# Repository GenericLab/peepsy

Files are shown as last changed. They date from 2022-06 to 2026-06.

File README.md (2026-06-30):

# Peepsy
Simple continuity tester based on Continuity Tester by David Johnson-Davies - http://www.technoblogy.com/show?1YON

# diy-CAD Handouts
diy-CAD (do-it-yourself Children Aided Design): The core idea of the workshop-kit is tool for creative designs of printed circuit boards, introducing basic concepts of Open Hardware being something to re-design for your own use. 

Read more about the creative PCB design methodology on this wiki: https://www.hackteria.org/wiki/Diy-CAD

## the schematics
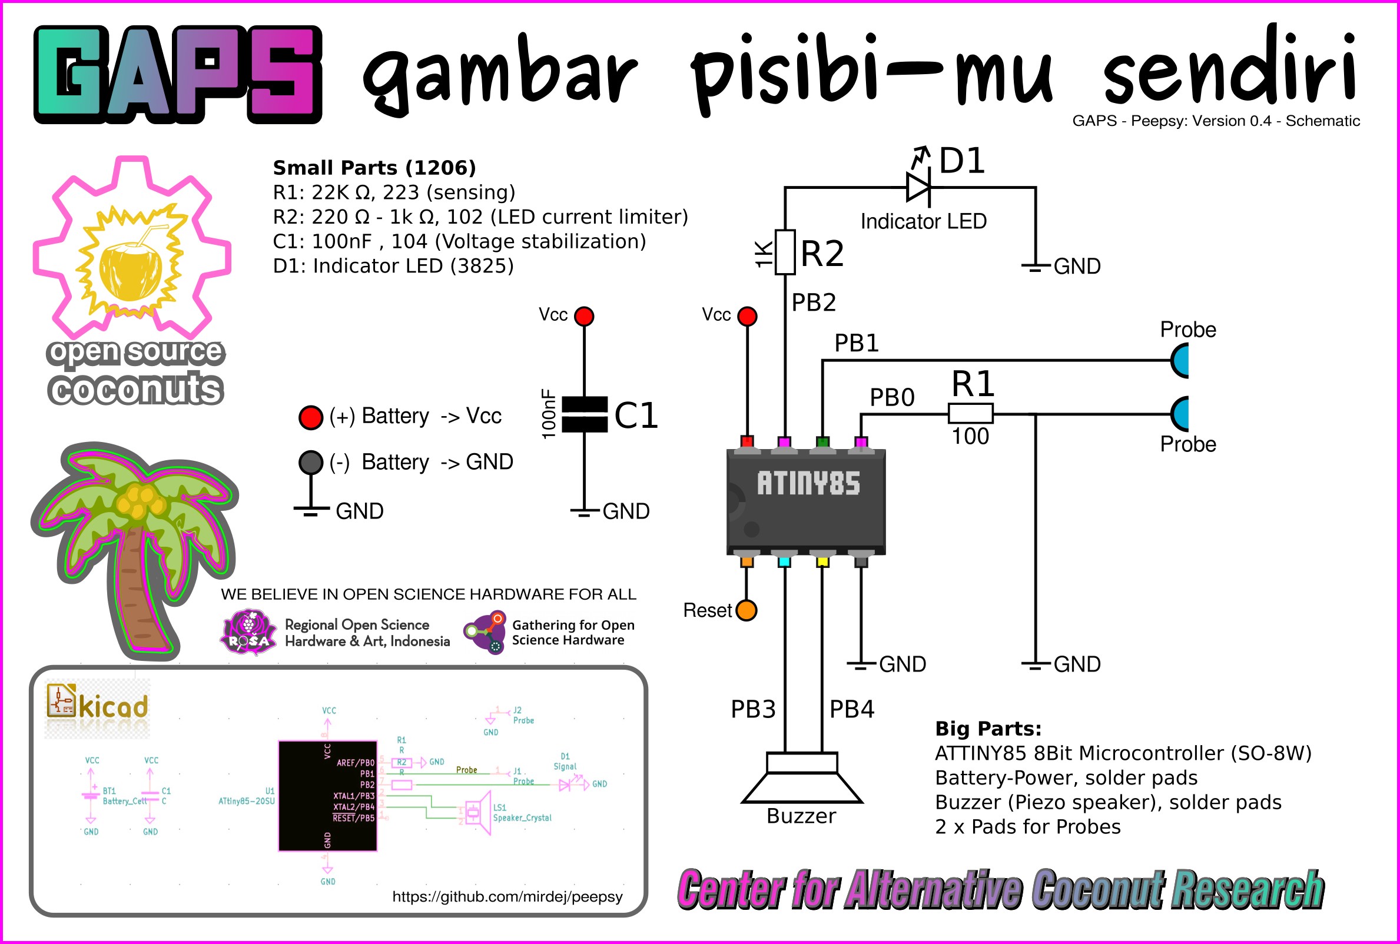
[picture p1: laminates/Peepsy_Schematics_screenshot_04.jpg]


## the BOM also know as the parts
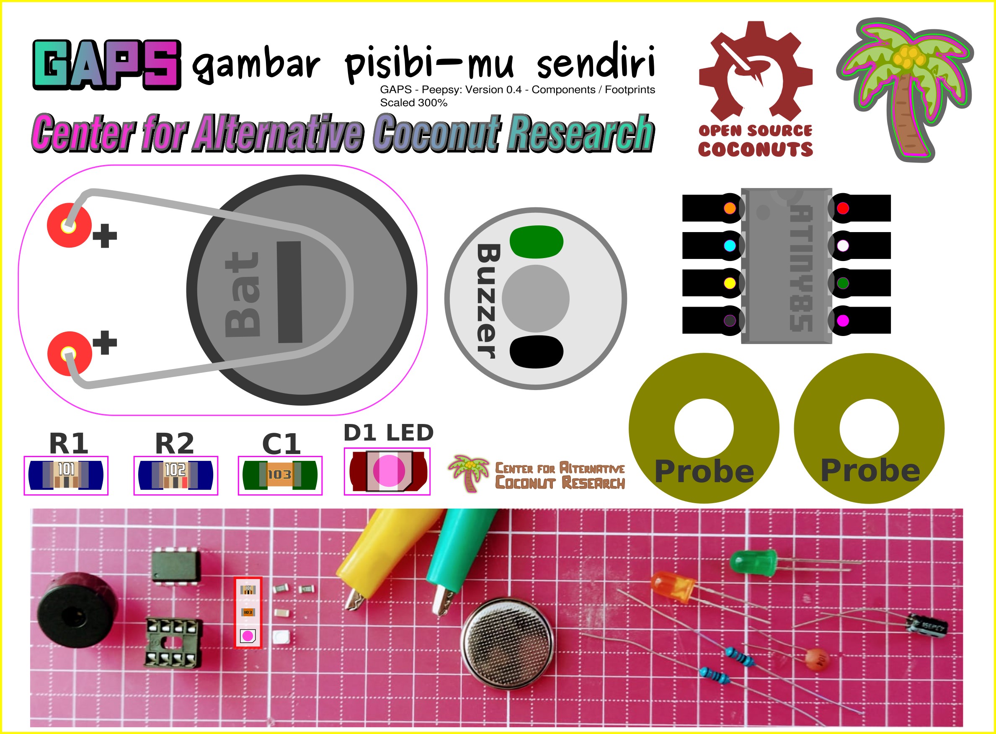
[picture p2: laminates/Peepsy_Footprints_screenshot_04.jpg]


# GAPS Workshops
## GAPS (GaPiSen) | gambar pisibi-mu sendiri - Creative PCB-design Workshop with Diy-CAD, Lifepatch 30. June 2022
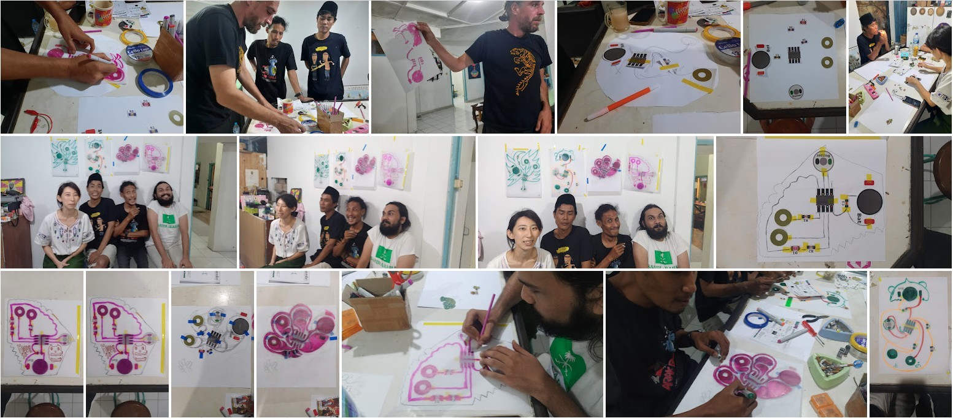
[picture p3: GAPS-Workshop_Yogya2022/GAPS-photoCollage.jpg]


## GAPS - Creative PCB-design Workshop, Electronic Wonderland August 2022
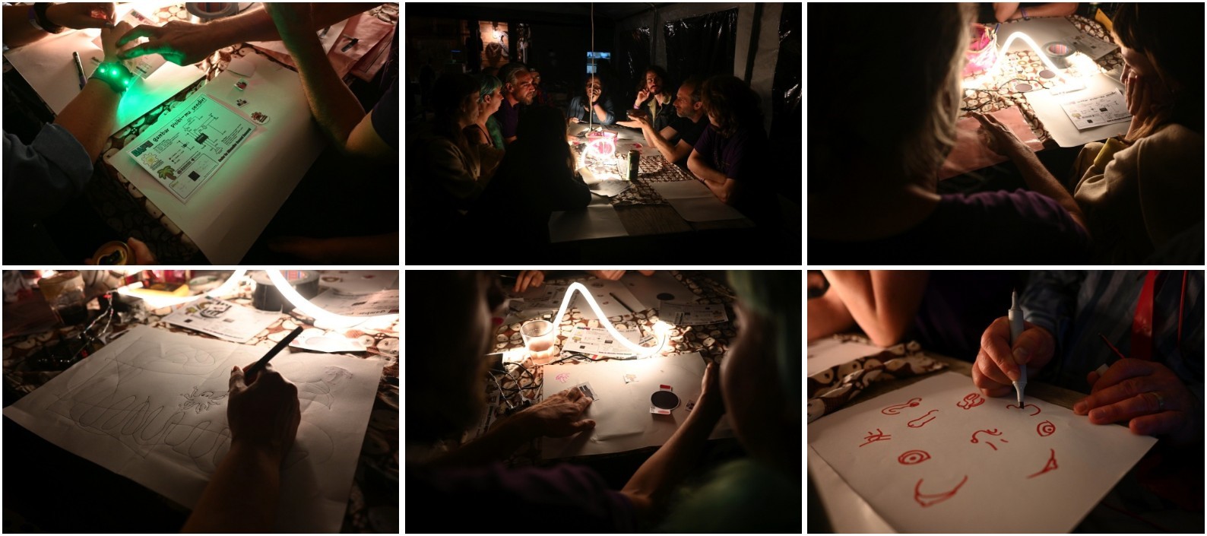
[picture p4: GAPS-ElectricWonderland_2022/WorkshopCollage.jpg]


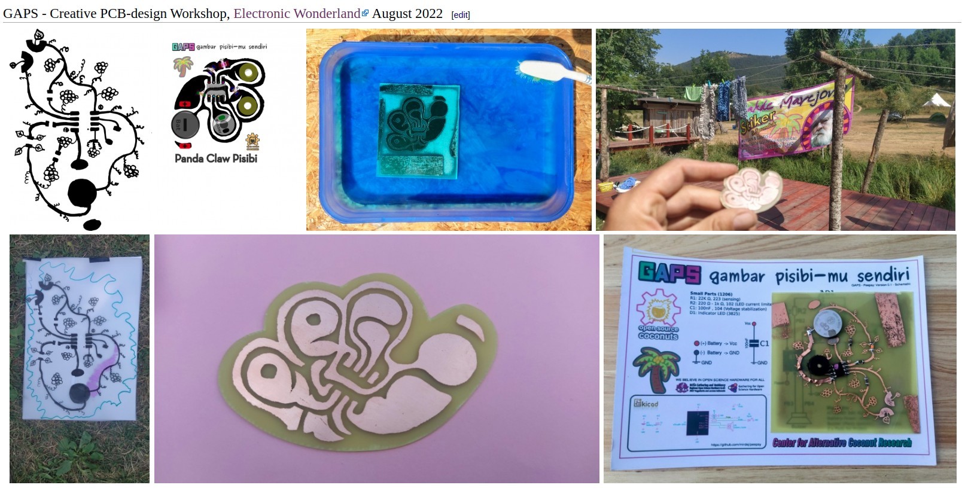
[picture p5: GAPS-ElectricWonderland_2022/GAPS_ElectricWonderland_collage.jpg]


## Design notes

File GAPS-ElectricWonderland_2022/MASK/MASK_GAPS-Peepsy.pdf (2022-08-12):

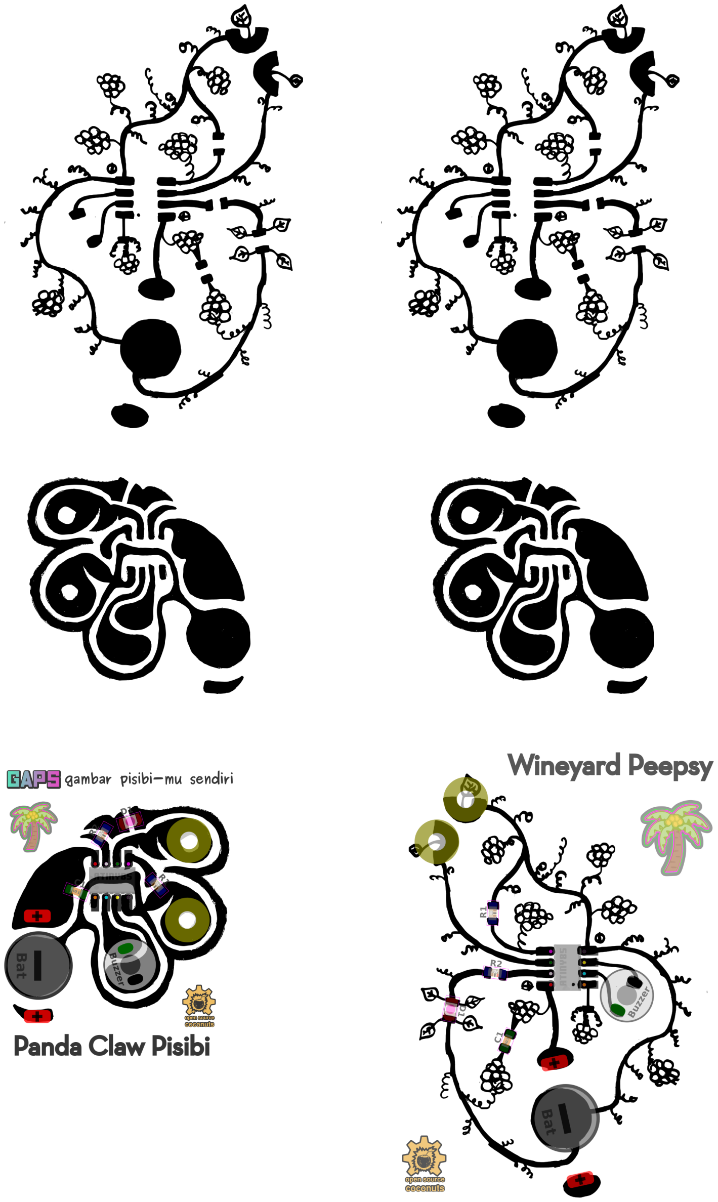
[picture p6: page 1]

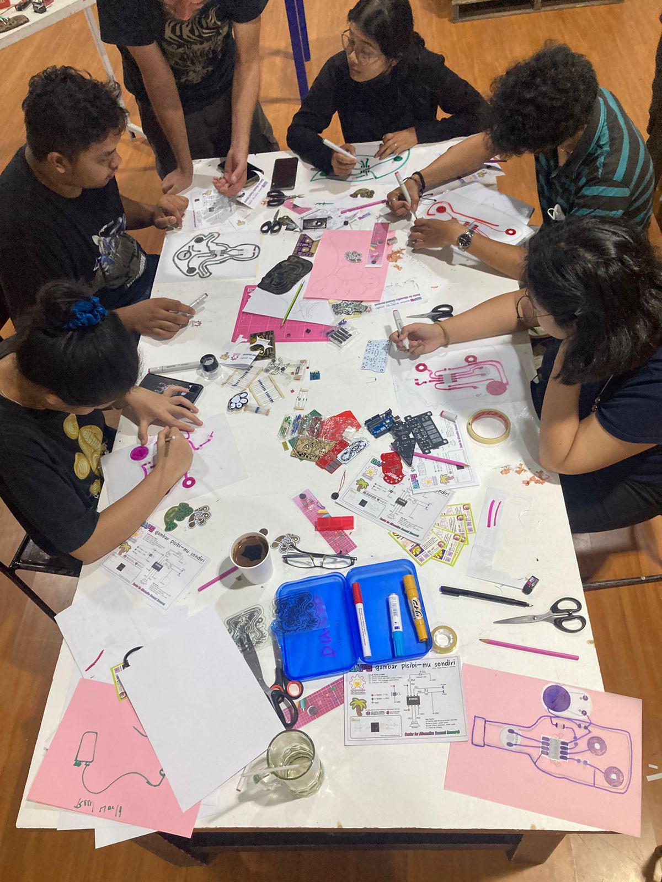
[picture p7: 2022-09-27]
GAPS_gudksul_sep2022/GAPS-Workshop_OverviewTable.jpg

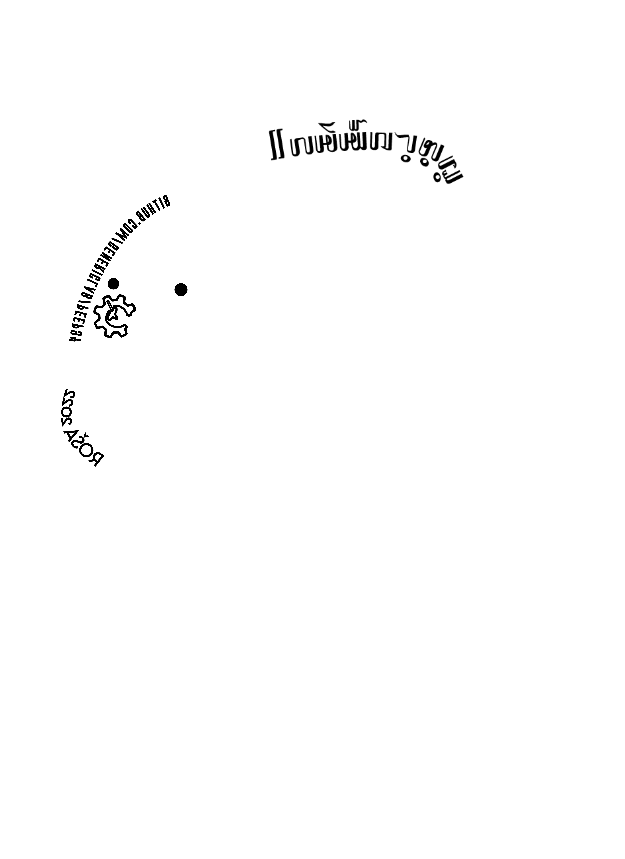
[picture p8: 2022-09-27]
GAPS-Workshop_Yogya2022/PandaClaw/.svg2shenzhen-cache/images/B.Mask_g1206.png

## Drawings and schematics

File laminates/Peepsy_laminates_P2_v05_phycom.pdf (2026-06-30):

104

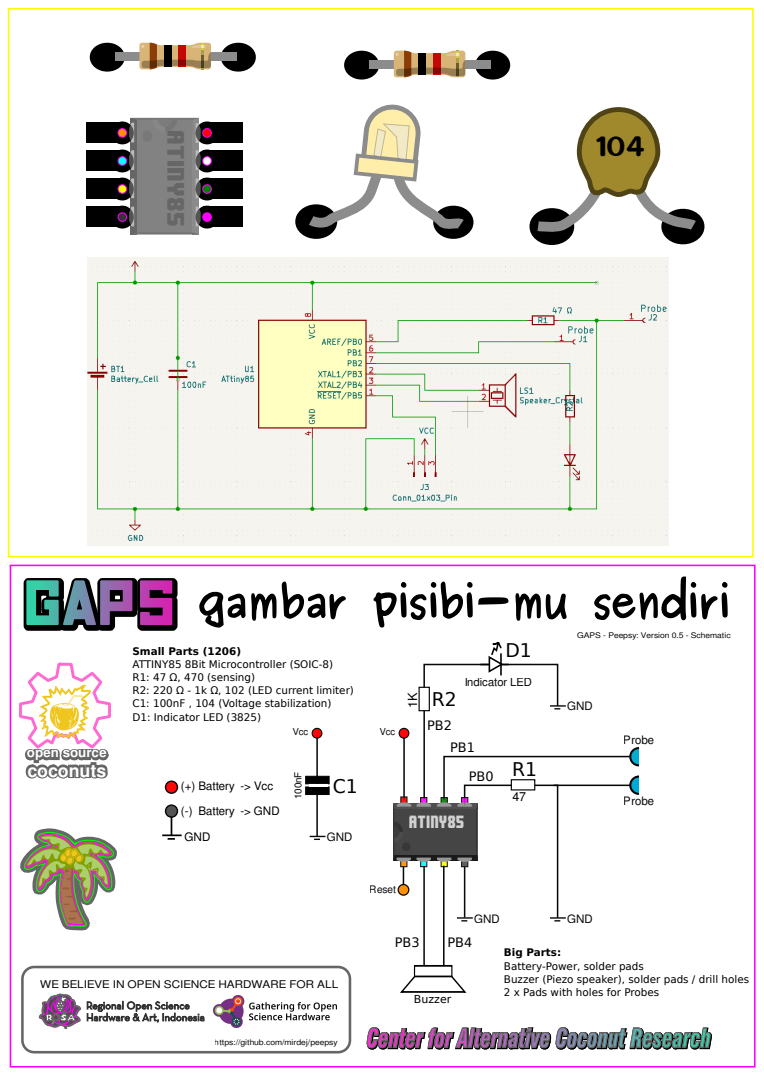
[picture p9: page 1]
ATiny85; Probe; Vcc; Indicator LED; GND; Buzzer; Reset; open source coconuts; (+) Battery -> Vcc; (-) Battery -> GND

S gambar pisibi-mu sendiri

GAPS - Peepsy: Version 0.5 - Schematic

Small Parts (1206)
ATTINY85 8Bit Microcontroller (SOIC-8)
R1: 47 Ω, 470 (sensing)
R2: 220 Ω - 1k Ω, 102 (LED current limiter)
C1: 100nF , 104 (Voltage stabilization)
D1: Indicator LED (3825)

Big Parts:
Battery-Power, solder pads
Buzzer (Piezo speaker), solder pads / drill holes
2 x Pads with holes for Probes

WE BELIEVE IN OPEN SCIENCE HARDWARE FOR ALL

https://github.com/mirdej/peepsy

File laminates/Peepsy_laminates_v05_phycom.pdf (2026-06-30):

G
G

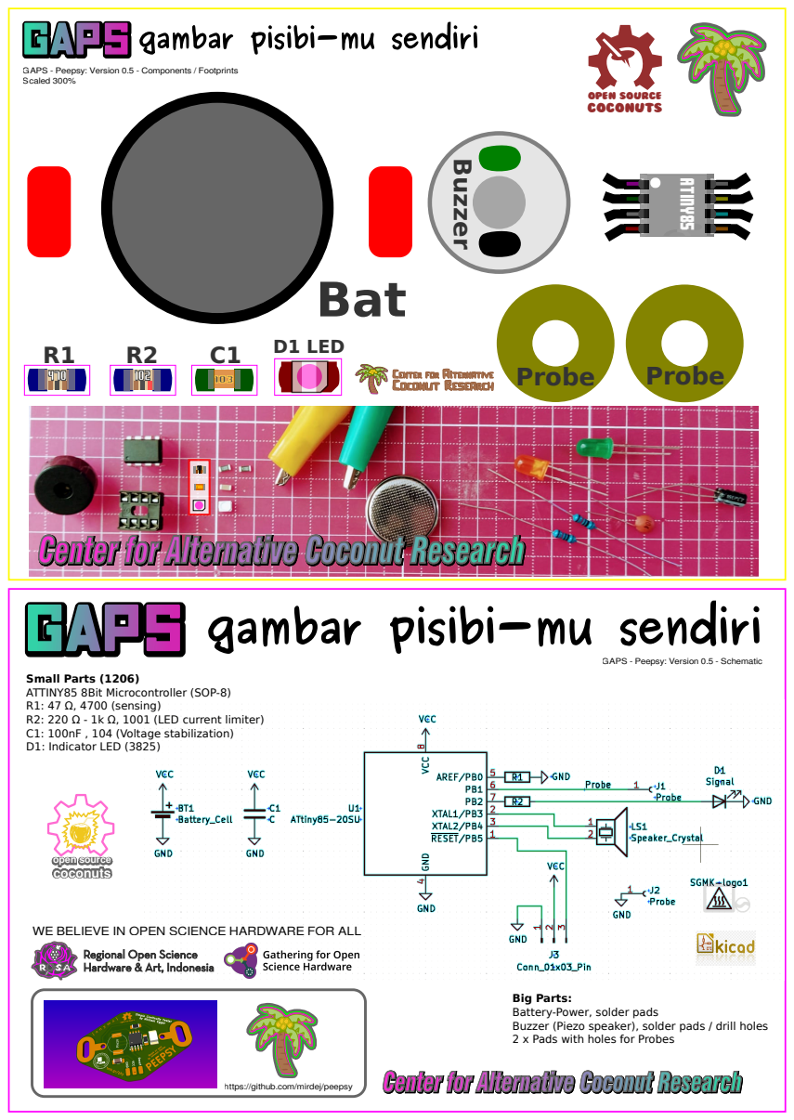
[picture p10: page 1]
D1 LED R2; Buzzer; ATiny85; Probe; Coconuts; Open Source; Bat; G GAPS; APS; gambar pisibi-mu sendiri; open source coconuts

S gambar pisibi-mu sendiri

GAPS - Peepsy: Version 0.5 - Components / Footprints
Scaled 300%

Center for Alternative
Coconut Research

GAPS - Peepsy: Version 0.5 - Schematic

Small Parts (1206)
ATTINY85 8Bit Microcontroller (SOP-8)
R1: 47 Ω, 4700 (sensing)
R2: 220 Ω - 1k Ω, 1001 (LED current limiter)
C1: 100nF , 104 (Voltage stabilization)
D1: Indicator LED (3825)

WE BELIEVE IN OPEN SCIENCE HARDWARE FOR ALL

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

https://github.com/mirdej/peepsy

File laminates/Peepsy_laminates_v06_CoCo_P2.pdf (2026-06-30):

104

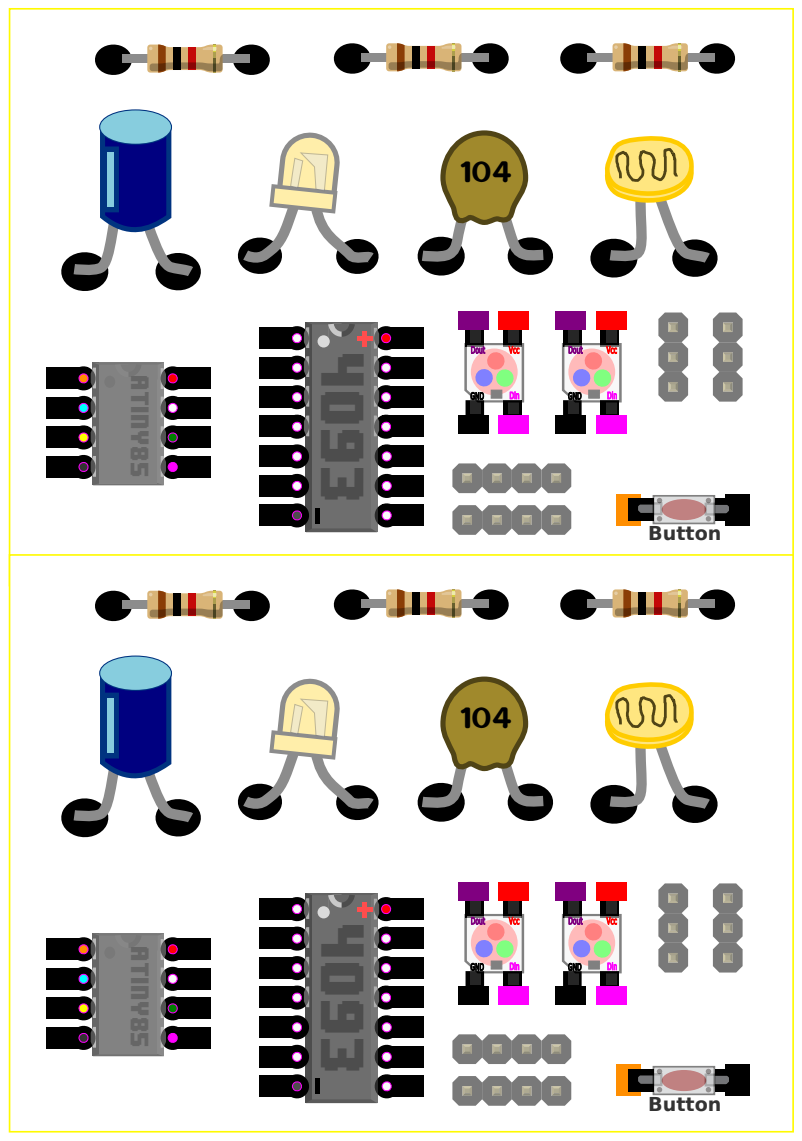
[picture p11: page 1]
Button; GND; Din; Dout; Vcc; ATiny85

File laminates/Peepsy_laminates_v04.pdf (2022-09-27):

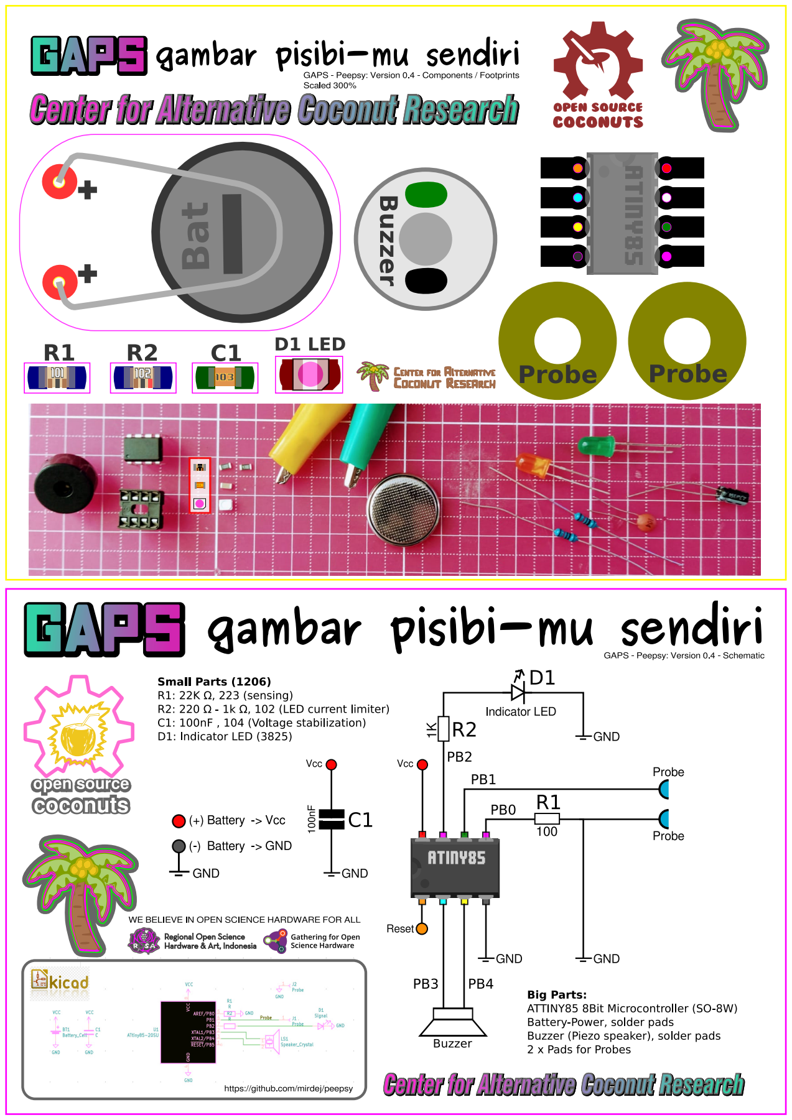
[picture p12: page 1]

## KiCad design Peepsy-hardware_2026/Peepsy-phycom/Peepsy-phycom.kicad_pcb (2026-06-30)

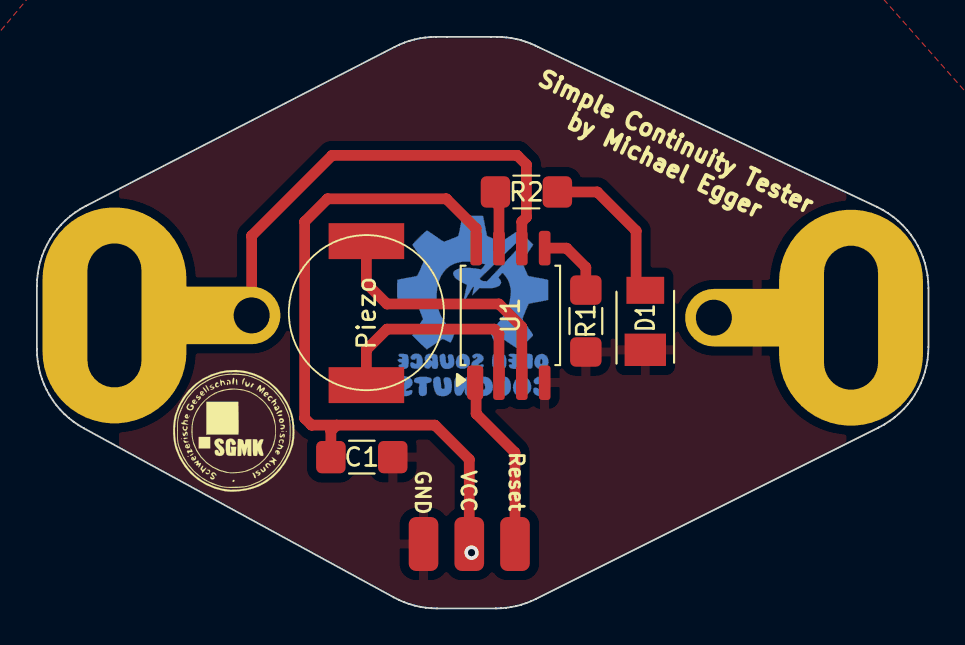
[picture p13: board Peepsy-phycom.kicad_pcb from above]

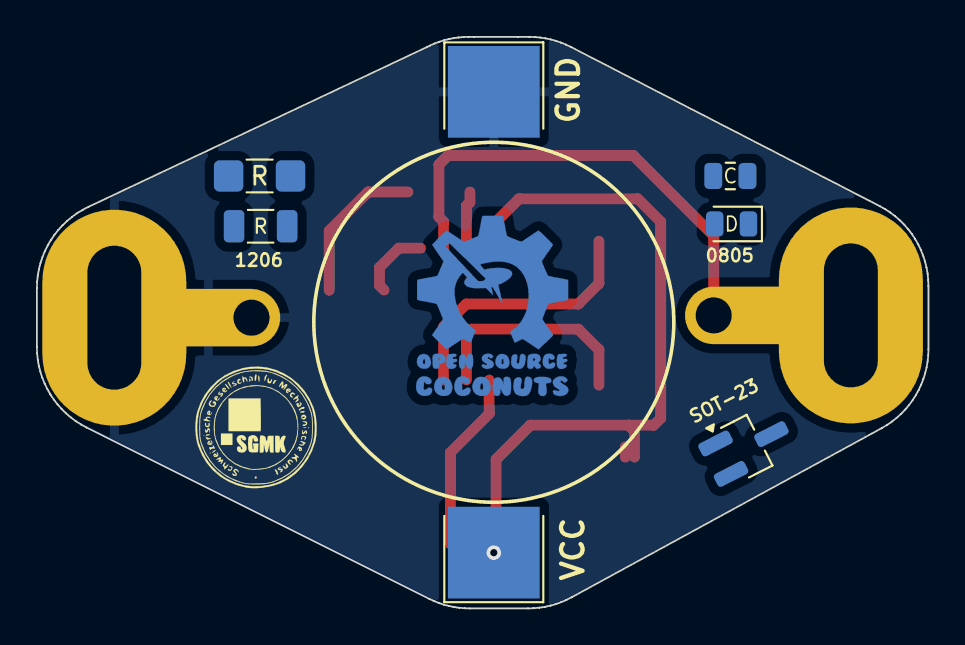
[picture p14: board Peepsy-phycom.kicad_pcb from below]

Board: 2 copper layers, 49.5 x 31.8 mm, 14 parts (5 on the bottom side), 9 nets.

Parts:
BT1: Battery_Cell; BatteryHolder_Keystone_1x2032
C: C_0805_2012Metric
C1: C; C_1210_noGND
D: LED_0805_2012Metric
D1: Signal; LED_PLCC_2835_Handsoldering
J1, J2: Probe; PeepsyPad_noGND
J3: Conn_01x03_Pin; smd-3pin
Piezo: Speaker_Crystal; Buzzer_CUI_CPT-9019S-SMT
R, R1, R2: R; R_1206_noGND
Ref**: Val**; Coconut_logo_sm
U1: ATtiny85-20SU; SOIC-8_Attiny85

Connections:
/Probe: J1.1, U1.6 (PB1)
GND: BT1.2 (-), C1.2, D1.1 (K), J2.1, J3.1, R1.1, U1.4 (GND)
unnamed: D1.2 (A), R2.1
unnamed: J3.3, U1.1 (~RESET/PB5)
unnamed: R1.2, U1.5 (AREF/PB0)
unnamed: R2.2, U1.7 (PB2)
unnamed: Piezo.1, U1.2 (XTAL1/PB3)
unnamed: Piezo.2, U1.3 (XTAL2/PB4)
VCC: BT1.1 (+), C1.1, J3.2, U1.8 (VCC)

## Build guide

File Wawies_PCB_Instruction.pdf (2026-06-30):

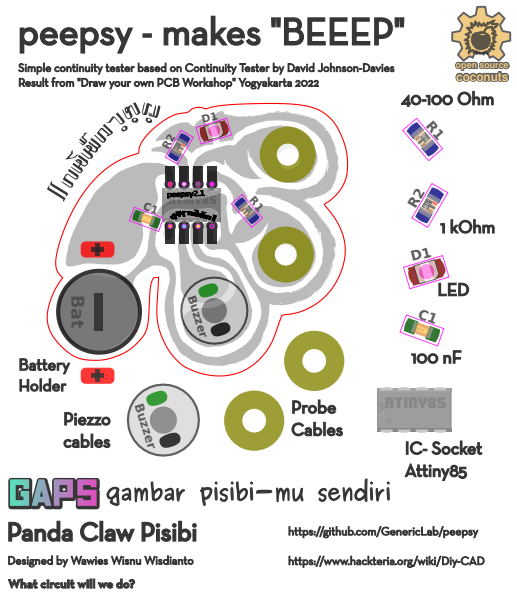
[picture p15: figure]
R21O2 Buzzer ATiny85; Bat; open source coconuts; ATiny85; Panda Claw Pisibi; GAPS gambar pisibi-mu sendiri; LED; 1 kOhm; 40-100 Ohm; IC- Socket Attiny85; Buzzer; Probe Cables; Battery Holder; Piezzo cables; https://github.com/GenericLab/peepsy; Designed by Wawies Wisnu Wisdianto; https://www.hackteria.org/wiki/Diy-CAD; What circuit will we do?; peepsy - makes "BEEEP"; peepsy2.1

Simple continuity tester based on Continuity Tester by David Johnson-Davies Result from "Draw your own PCB Workshop" Yogyakarta 2022

The example circuit is based on the peepsy, by Michael Egger (a.n.y.m.a.) and it has even a practical function as a continuity tester, the most useful tool to test if a connection is present, in a cable or on a circuit. It's the "peep" that is one of the functions of all multimeters, and usually the one we use the most! The circuit is very simple, 1 capacitor, 2 resistors, 1 LED, a buzzer to make the "beep", a coin battery holder and an μ-controller (the Attiny85). Due to the special software on the attiny, it will "sleep" all the time, and only use a little electricity when testing, so the battery last almost forever!

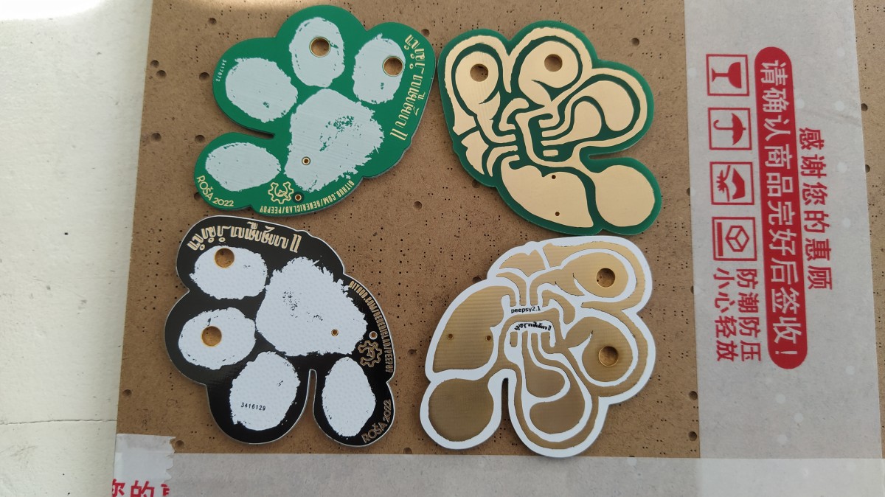
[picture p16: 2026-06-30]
GAPS-Workshop_Yogya2022/PandaClaw/PandaPepsy_manufacturedBoards.jpg

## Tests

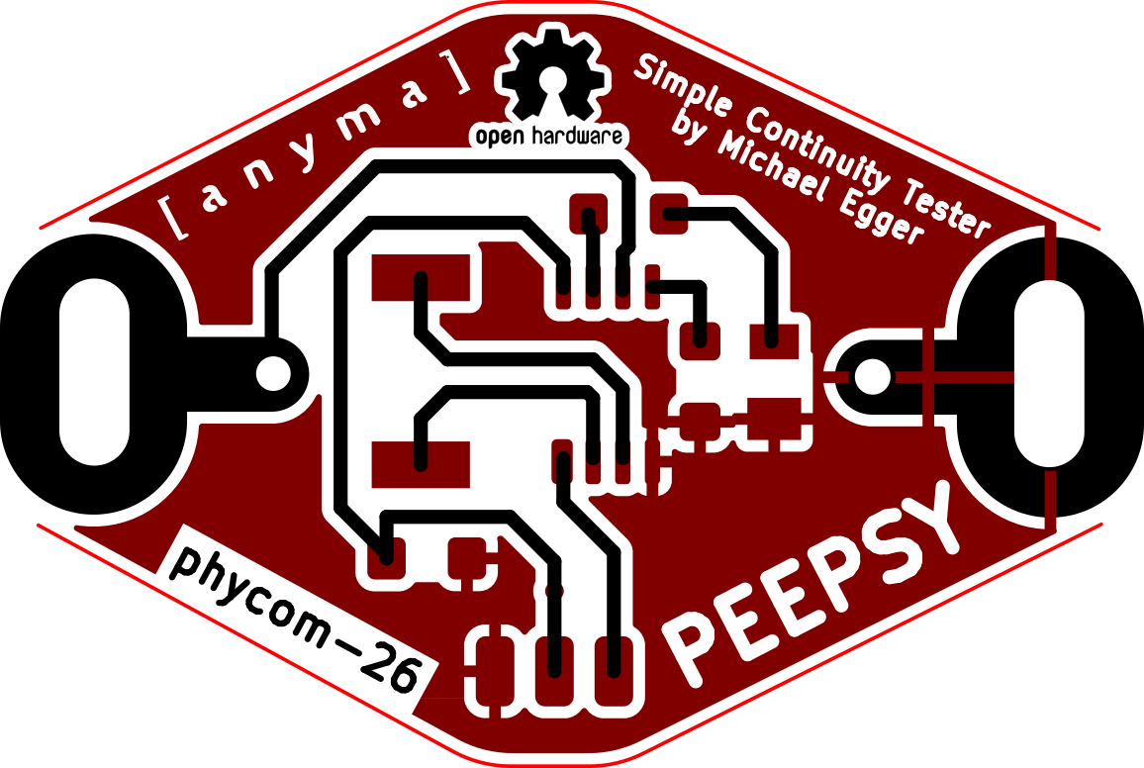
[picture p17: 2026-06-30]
Peepsy-hardware_2026/Peepsy-phycom/tests/g108.png

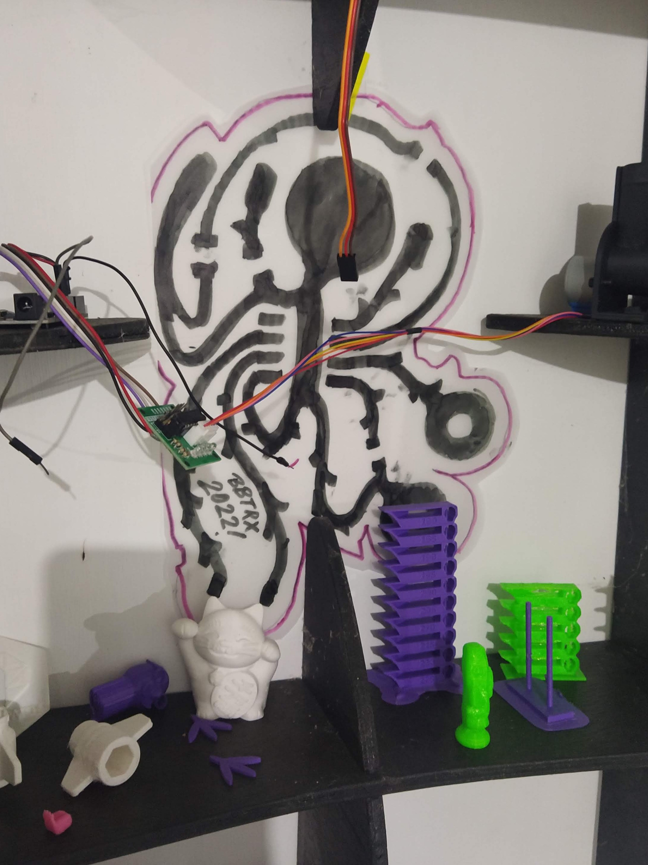
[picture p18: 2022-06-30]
laminates/GAPS_test_fiky.jpg

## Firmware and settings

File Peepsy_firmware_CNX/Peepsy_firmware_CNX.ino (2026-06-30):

/* ---------------------------------------------------------------------------------------


	PEEPSY 
	
	by Michael Egger [ a n y m a ]
	 
	based on Continuity Tester by David Johnson-Davies - www.technoblogy.com - 18th November 2017
	ATtiny85 @ 1 MHz (internal oscillator; BOD disabled)
	 
	CC BY 4.0
	Licensed under a Creative Commons Attribution 4.0 International license: 
	http://creativecommons.org/licenses/by/4.0/

	Bytebeat mod: viznut-style algorithmic sound instead of boring beep.
	Each probe touch cycles to a different formula.

--------------------------------------------------------------------------------------- */

#include <avr/sleep.h>
#include <avr/power.h>

const int				Pin_Led_Wake	= 5;
const int				Pin_Led_Sense	= 2;
const int				Pin_Reference	= 0;		// AIN0
const int				Pin_Probe		= 1;		// AIN1
const int				Pin_Speaker_A	= 4;		// OC1B
const int				Pin_Speaker_B	= 3;		// ~OC1B (complementary)

const unsigned long		Timeout = (unsigned long)60*1000; // One minute
volatile unsigned long	Time;

// Bytebeat state
static uint16_t t = 0;
static uint8_t  formula = 0;
static bool     wasSensing = false;

// Speaker pin bitmask for atomic PORTB writes
#define SPK_MASK ((1 << Pin_Speaker_A) | (1 << Pin_Speaker_B))

// Number of bytebeat formulas available
#define NUM_FORMULAS 4

// ----------------------------------------------------------------------------------------
// Pin change interrupt service routine - resets sleep timer
ISR (PCINT0_vect) {
	Time = millis();
}

// ----------------------------------------------------------------------------------------
// Viznut-style bytebeat: returns 8-bit sample
// All formulas chosen to be cheap on ATtiny85 (no HW multiply)
static uint8_t bytebeat(uint16_t t) {
	switch (formula) {
		case 0:  return t * ((t >> 5) | (t >> 8));                              // classic viznut
		case 1:  return (t * 5 & (t >> 7)) | (t * 3 & (t >> 10));              // shift-only harmonics
		case 2:  return t * ((t >> 11) & (t >> 8) & 123 & (t >> 3));           // rhythmic crunch
		case 3:  return (t | (t >> 9) | (t >> 7)) * 10 + 4 * (t & (t >> 13)); // glitchy melody
		default: return 0;
	}
}

// ----------------------------------------------------------------------------------------
void setup () {
	pinMode(Pin_Reference,	INPUT_PULLUP);
	pinMode(Pin_Probe,		INPUT_PULLUP);
	pinMode(Pin_Led_Sense,	OUTPUT);
	pinMode(Pin_Led_Wake,	OUTPUT);
	pinMode(Pin_Speaker_A,	OUTPUT);
	pinMode(Pin_Speaker_B,	OUTPUT);
	
	// Ensure analog comparator is on, not connected to timer, no bandgap ref
	ACSR = 0;

	// No Timer1 for sound — we bitbang the piezo directly
	TCCR1 = 0;
	GTCCR = 0;

	//Pin-change interrupt
	PCMSK = 1 << Pin_Probe;
	GIMSK = GIMSK | 1 << PCIE;
	
	// Power saving
	ADCSRA &= ~(1 << ADEN);
	PRR = 1 << PRUSI | 1 << PRADC;
	set_sleep_mode(SLEEP_MODE_PWR_DOWN);
	
	// Start running
	//digitalWrite(Pin_Led_Wake, HIGH);
	Time = millis();
}

// ----------------------------------------------------------------------------------------
void loop() {
	// Quiet the speaker before reading comparator — avoids noise coupling
	uint8_t pb = PORTB & ~SPK_MASK;          // both speaker pins LOW
	PORTB = pb;
	delayMicroseconds(10);                    // let comparator settle

	bool Sense = ACSR >> ACO & 1;

	if (Sense) {
		// New touch? Cycle to next formula
		if (!wasSensing) {
			formula = (formula + 1) % NUM_FORMULAS;
			wasSensing = true;
		}

		// Compute bytebeat sample, 1-bit threshold → push-pull piezo
		uint8_t val = bytebeat(t);
		if (val & 0x80) {
			PORTB = (pb | (1 << Pin_Speaker_A));    // PB4=H, PB3=L (atomic)
		} else {
			PORTB = (pb | (1 << Pin_Speaker_B));    // PB4=L, PB3=H (atomic)
		}
		t++;
		PORTB |= (1 << Pin_Led_Sense);

		// Pad to ~8kHz sample rate (minus overhead for bytebeat + comparator settle)
		delayMicroseconds(40);

	} else {
		if (wasSensing) {
			wasSensing = false;
		}
		// Speaker already silenced above
		PORTB &= ~(1 << Pin_Led_Sense);
	}
	
	// Go to sleep?
	if (millis() - Time > Timeout) {
		PORTB &= ~(SPK_MASK | (1 << Pin_Led_Sense));
		digitalWrite(Pin_Led_Wake, 	LOW);
		pinMode(Pin_Reference, 		INPUT);				// Turn off pullup to save power

		sleep_enable();
		sleep_cpu();
		// Carry on here when we wake up

		pinMode(Pin_Reference, INPUT_PULLUP);
		digitalWrite(Pin_Led_Wake, 	HIGH);
	}
}

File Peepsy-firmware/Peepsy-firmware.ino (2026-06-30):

/* ---------------------------------------------------------------------------------------

	PEEPSY 
	
	by Michael Egger [ a n y m a ]
	 
	based on Continuity Tester by David Johnson-Davies - www.technoblogy.com - 18th November 2017
	ATtiny85 @ 1 MHz (internal oscillator; BOD disabPin_Led_Wake)
	 
	CC BY 4.0
	Licensed under a Creative Commons Attribution 4.0 International license: 
	http://creativecommons.org/licenses/by/4.0/
	
--------------------------------------------------------------------------------------- */

#include <avr/sleep.h>
#include <avr/power.h>

const int					Pin_Led_Wake		= 5;
const int					Pin_Led_Sense		= 2;
const int					Pin_Reference		= 0;		// AIN0
const int					Pin_Probe			= 1;		// AIN1
const int					Pin_Speaker_A		= 4;
const int					Pin_Speaker_B		= 3;

const unsigned long		Timeout = (unsigned long)60*1000; // One minute
volatile unsigned long	Time;

// ----------------------------------------------------------------------------------------
// Pin change interrupt service routine - resets sleep timer
ISR (PCINT0_vect) {
	Time = millis();
}

// ----------------------------------------------------------------------------------------
void Beep () {
	TCCR1 = TCCR1 | 3;											// Counter = clock/4
	digitalWrite(Pin_Led_Sense, HIGH);
} 

// ----------------------------------------------------------------------------------------
void NoBeep () {
	TCCR1 = TCCR1 & ~3;											// Counter stopped
	digitalWrite(Pin_Led_Sense, LOW);
}


// ----------------------------------------------------------------------------------------
void setup () {
	pinMode(Pin_Reference,	INPUT_PULLUP);
	pinMode(Pin_Probe,		INPUT_PULLUP);
	pinMode(Pin_Led_Sense,	OUTPUT);
	pinMode(Pin_Led_Wake,	OUTPUT);
	pinMode(Pin_Speaker_A,	OUTPUT);
	pinMode(Pin_Speaker_B,	OUTPUT);
	
 	 // Setup beep
 	TCCR1 = 1 << CTC1 | 0 << COM1A0 | 0 << CS10;  			// CTC mode, counter stopped
	GTCCR = 1 << COM1B0;									// Toggle OC1B (PB4 and PB3 in PM Mode )
	GTCCR |= 1 << PWM1B;									// PWM Mode
	OCR1C = 208;											// Plays 1042Hz (C6)
	OCR1B = 119;											// at duty cycle 50

	
	//Pin-change interrupt
	PCMSK = 1 << Pin_Probe;									// Pin change interrupt on Pin_Probe
	GIMSK = GIMSK | 1 << PCIE;								// Enable pin-change interrupt
	
	// Power saving
	ADCSRA &= ~(1 << ADEN);									// Disable ADC to save power
	PRR = 1 << PRUSI | 1 << PRADC;							// Turn off unused clocks
	set_sleep_mode(SLEEP_MODE_PWR_DOWN);
	
	// Start running
	//digitalWrite(Pin_Led_Wake, HIGH);
	Time = millis();
}

// ----------------------------------------------------------------------------------------
void loop() {
	bool Sense = ACSR>>ACO & 1;
	if (Sense) Beep(); else NoBeep();
	
	// Go to sleep?
	if (millis() - Time > Timeout) {
		digitalWrite(Pin_Led_Sense, LOW);
		digitalWrite(Pin_Led_Wake, 	LOW);
		pinMode(Pin_Reference, 		INPUT);								// Turn off pullup to save power
		sleep_enable();
		sleep_cpu();
		// Carry on here when we wake up
		pinMode(Pin_Reference, INPUT_PULLUP);
		digitalWrite(Pin_Led_Wake, 	HIGH);
	}
}

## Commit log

2022-06-30 adding diy-CAD files
2022-09-27 adding panda pisibi and new laminates v0.4
    [Wawies_PCB_inv.kicad_pcb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]
2024-09-11 Soldering instructions for PandaClaw Peepsy
2026-06-30 renaming and adding new hardware
    [Peepsy-phycom-B_Cu.gbr, Peepsy-phycom-B_Mask.gbr, Peepsy-phycom-B_Silkscreen.gbr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]
